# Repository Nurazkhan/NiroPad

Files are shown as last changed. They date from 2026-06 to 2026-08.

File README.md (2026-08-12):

# NiroPad
Simlple macropad to make your computer usage even faster.

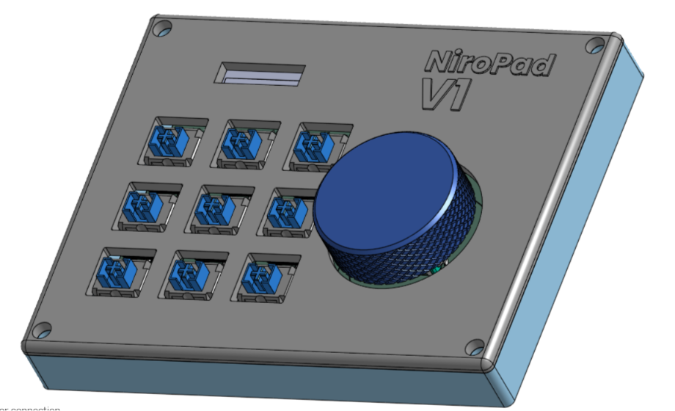
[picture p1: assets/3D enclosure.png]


I made this macropad with the help of hackClub. You can find useful references/examples in [Hackpad]([url](https://stardance.hackclub.com/missions/hackpad)) section.
## Features
* 128x32px for cool animations.
* 9 Cherry MX style Keys for best experience.
* 1 EC11 encoder to control with accuracy.
* Bright 18 RGB LEDS to make it GLOW. (9 for underglow, 4 under encoder, 4 near display, 1 under display)
* 3D printed perfect case with personal mentions.
* QMK Firmware

## CAD Model
CAD consists of a total of 3 parts: Case, Cover, Knob.
The case and the cover for it fit together with 4*M3 screws and heatset inserts.
The knob is attached to the encoder by friction.
The case has space for keys and displays, so it fits perfectly.
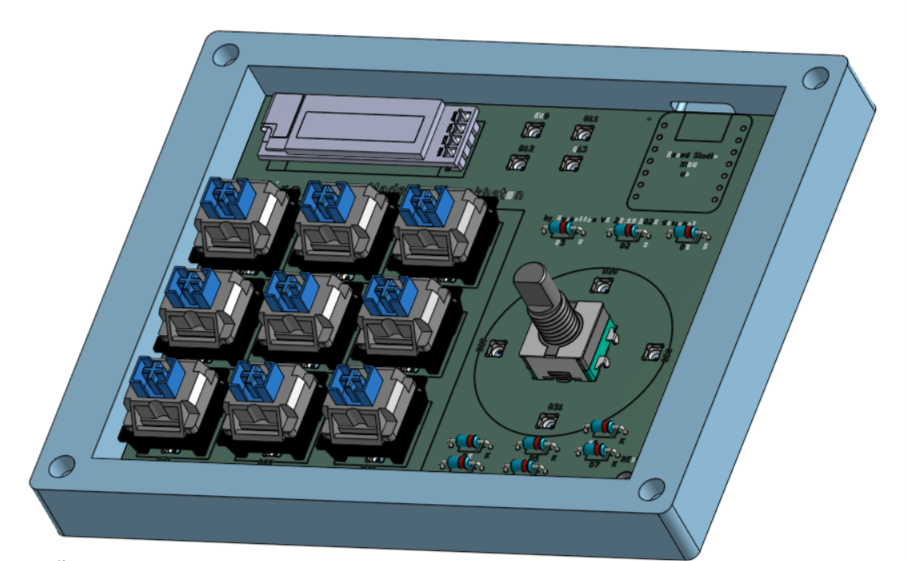
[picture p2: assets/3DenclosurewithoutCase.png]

Made in OnShape. by Nurazkhan (me).

## PCB
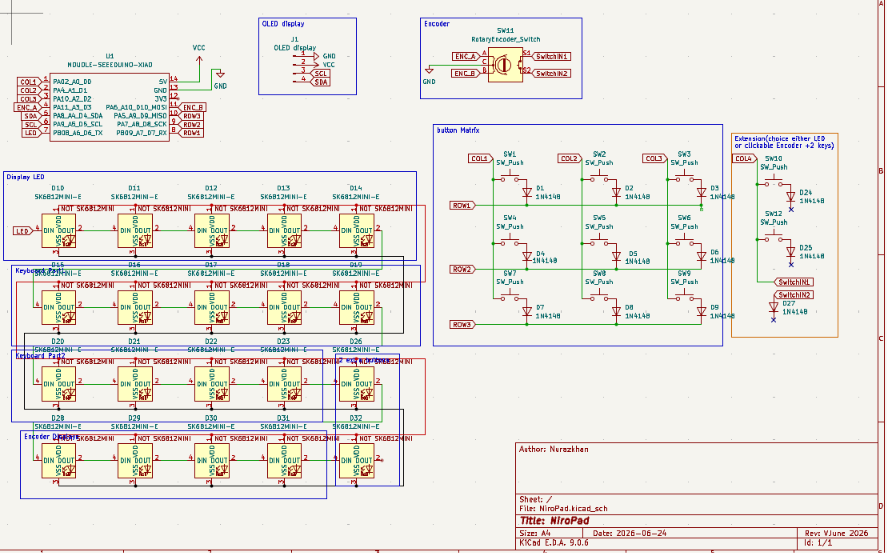
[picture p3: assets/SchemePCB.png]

Schematic was made in KiCad.
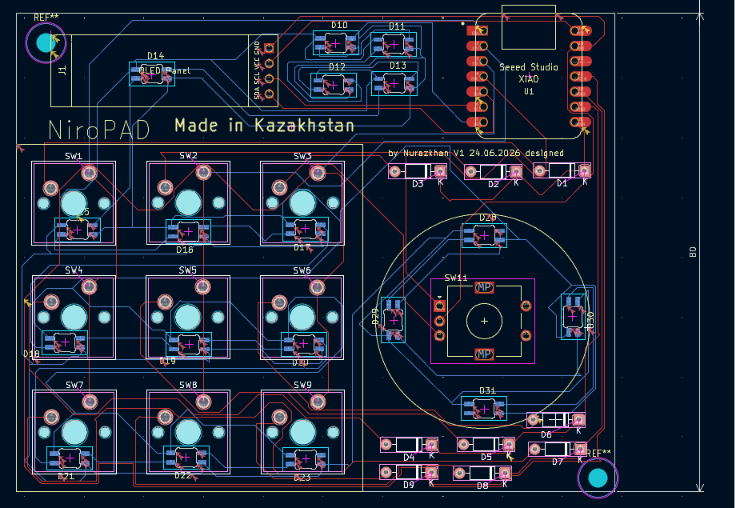
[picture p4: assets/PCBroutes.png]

PCB routing was also made in KiCad Software. Footprints for keys were imported from recommended resources; you can also find [it]([url](https://github.com/sszczep/kicad-libraries)).

## Firmware Overview
The NiroPad Works on QMK firmware.
Main functions are:
* 9 keys for the number section. (My laptop doesn't have a separate keyboard section for numbers).
* Encoder to control volume.
* Dynamic LED control based on CAPS LOCK state.
* OLED showing the mode of the keyboard.
In the future, have to add more functions (changing modes from number sections to shortcuts, or media control, etc.
Also, planning to add animations to the OLED display.

## BOM
 * 9 Cherry MX style switches
 * 9 1N4148 diodes
 * 1 Custom PCB
 * 0.91 SSD1306 OLED display 128x32px
 * Xiao Speeed RPI2040 microcontroller
 * 3d printer enclosure (top and bottom) and knob for encoder
 * EC11 Encoder
 * 4 M3*16mm screws
 * 4 M3*5m*4mm heatset inserts

The process of designing and creation you can see in the journals folder.

Thank you!
#hackClub

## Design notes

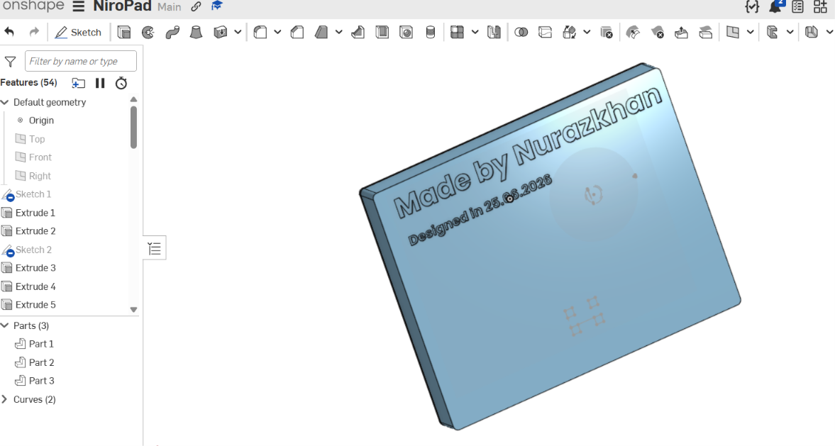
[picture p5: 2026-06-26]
assets/Back.png

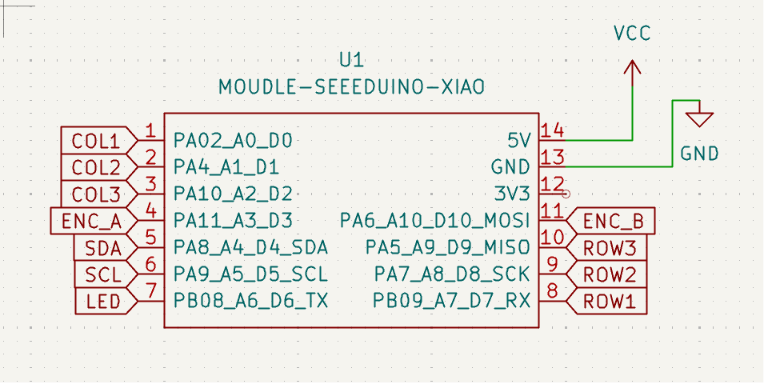
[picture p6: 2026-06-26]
assets/RPI2040scheme.png

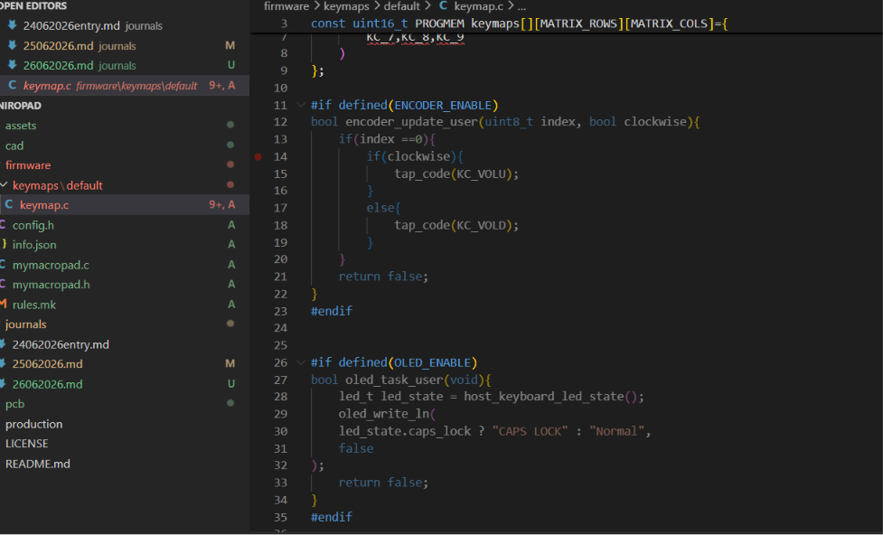
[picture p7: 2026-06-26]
assets/codeQMK.png

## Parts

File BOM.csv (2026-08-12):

Item Name | Qty | Price (total) (USD) | Item link | Notes
Cherry MX style switches | 9 | $9.25 | https://aliexpress.ru/item/32839844484.html?sku_id=65063435222 | This is part of MacroPad Kit
1N4148 diodes | 9 | $0.45 | https://aliexpress.ru/item/1005003194692663.html?sku_id=12000024603253281 | This is part of MacroPad Kit
Custom PCB | 1 |  |  | This is part of MacroPad Kit. Made by third parties(JLCPCB, PCBWAY)
0.91 SSD1306 OLED display 128x32px | 1 | $1.64 | https://aliexpress.ru/item/1005008472586580.html?sku_id=12000045297338933 | This is part of MacroPad Kit
Xiao Speeed RPI2040 microcontroller | 1 | $8.00 | https://aliexpress.ru/item/1005007427287029.html?sku_id=12000040716641980 | This is part of MacroPad Kit
3d printer enclosure (top and bottom) and knob for encoder |  |  |  | This is part of MacroPad Kit (3d printed)
EC11 Encoder | 1 | $0.67 | https://aliexpress.ru/item/1005006693443387.html?sku_id=12000048311239356 | This is part of MacroPad Kit
M3*16mm screws | 4 | $2.16 | https://aliexpress.ru/item/1005002364568213.html?sku_id=12000020355723657 | This is part of MacroPad Kit
M35m4mm heatset inserts | 4 | $1.41 | https://aliexpress.ru/item/1005008666672949.html?sku_id=12000046157335344 | This is part of MacroPad Kit
Total Price (USD): | $14.33

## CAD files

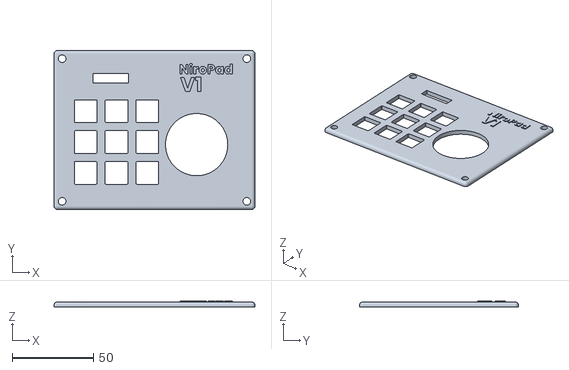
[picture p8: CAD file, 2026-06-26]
production/NiroPad - EnclosureTop.stl
124.0 x 98.0 x 3.50

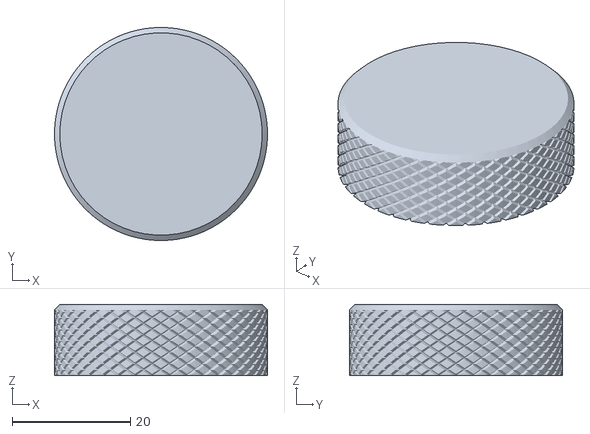
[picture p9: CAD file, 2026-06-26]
production/NiroPad - Knob.stl
36.0 x 36.0 x 12.0

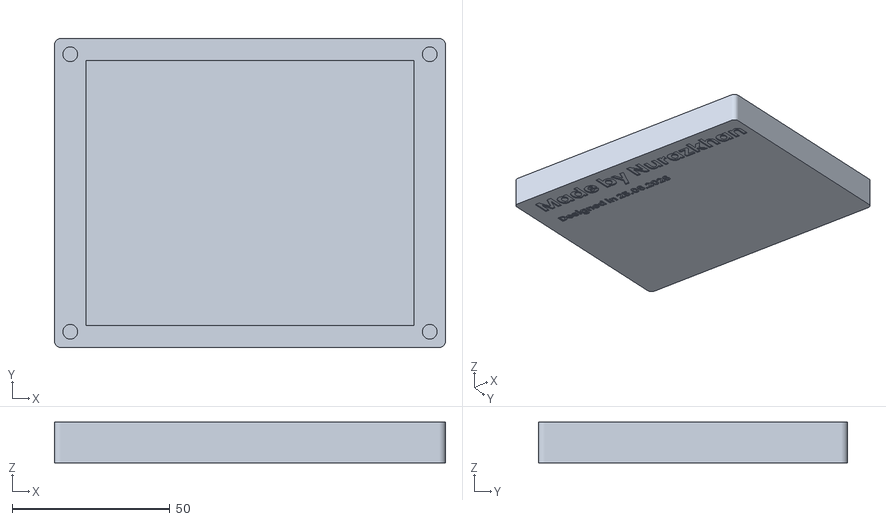
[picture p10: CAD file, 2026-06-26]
production/NiroPad - EnclosureBack.stl
124.0 x 98.0 x 13.0

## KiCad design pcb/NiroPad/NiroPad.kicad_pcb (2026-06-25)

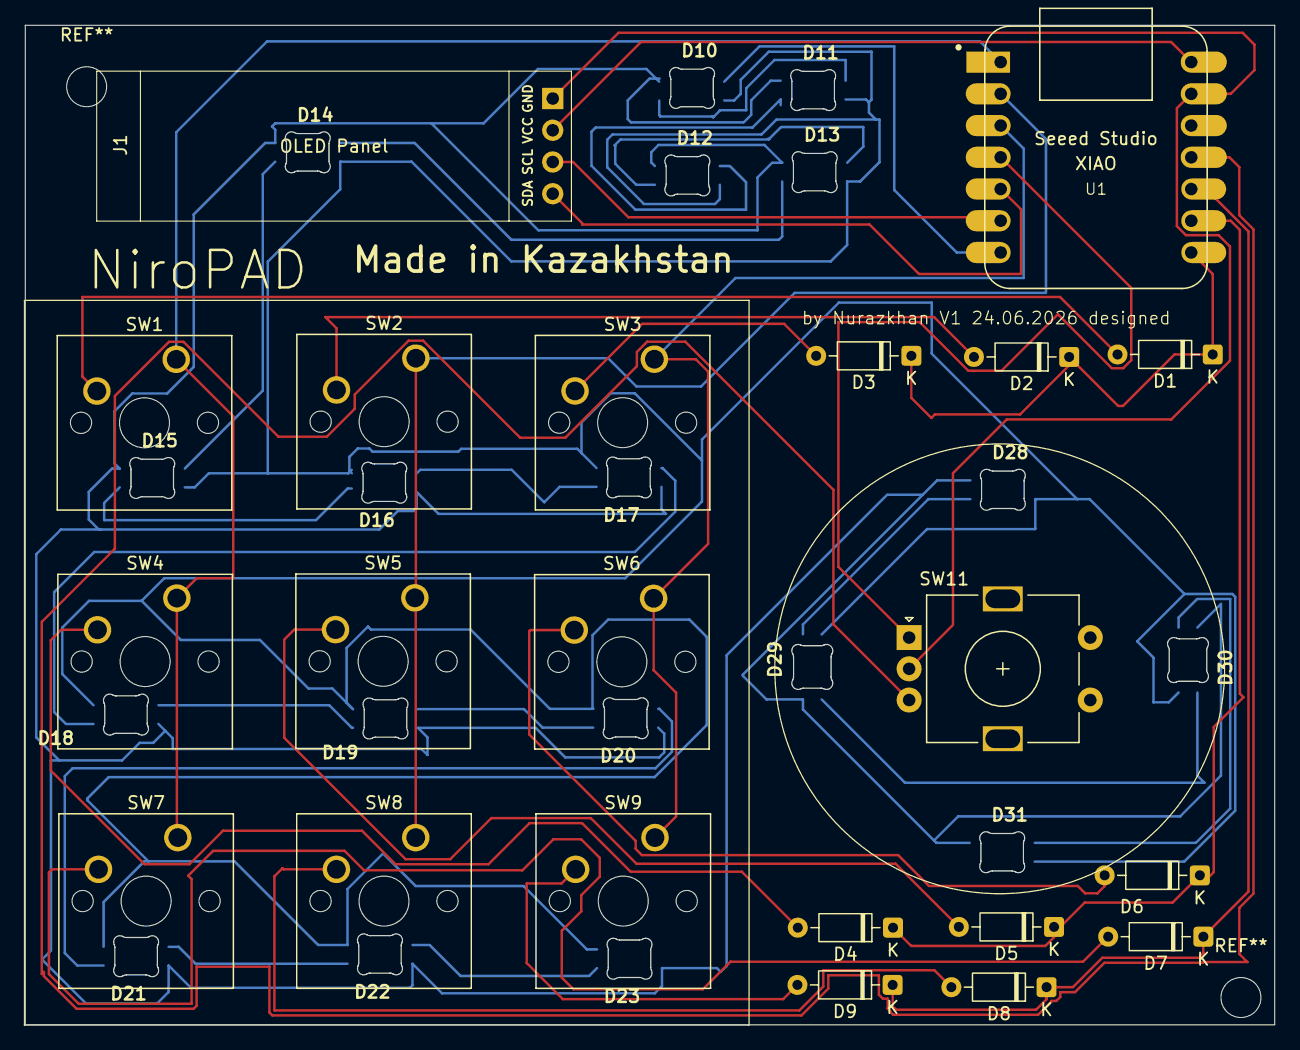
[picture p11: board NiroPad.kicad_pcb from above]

Board: 2 copper layers, 100.0 x 80.0 mm, 39 parts (0 on the bottom side), 40 nets.

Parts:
D1, D2, D3, D4, D5, D6, D7, D8, D9: 1N4148; D_DO-35_SOD27_P7.62mm_Horizontal
D10, D11, D12, D13, D14, D15, D16, D17, D18, D19, D20, D21, D22, D23, D28, D29, D30, D31: SK6812MINI-E; SK6812MINI-E_fixed
J1: OLED display; SSD1306-0.91-OLED-4pin-128x32
SW1, SW2, SW3, SW4, SW5, SW6, SW7, SW8, SW9: SW_Push; footprint
SW11: RotaryEncoder_Switch; RotaryEncoder_Alps_EC11E-Switch_Vertical_H20mm
U1: MOUDLE-SEEEDUINO-XIAO; XIAO-Generic-Hybrid-14P-2.54-21X17.8MM

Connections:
COL1: SW1.1, SW4.1, SW7.1, U1.1 (PA02_A0_D0)
COL2: SW2.1, SW5.1, SW8.1, U1.2 (PA4_A1_D1)
COL3: SW3.1, SW6.1, SW9.1, U1.3 (PA10_A2_D2)
ENC_A: SW11.A, U1.4 (PA11_A3_D3)
ENC_B: SW11.B, U1.11 (PA6_A10_D10_MOSI)
GND: J1.1, SW11.C, U1.13 (GND)
LED: D10.4 (DIN), U1.7 (PB08_A6_D6_TX)
unnamed: D1.2 (A), SW1.2
unnamed: D2.2 (A), SW2.2
unnamed: D3.2 (A), SW3.2
unnamed: D4.2 (A), SW4.2
unnamed: D5.2 (A), SW5.2
unnamed: D6.2 (A), SW6.2
unnamed: D7.2 (A), SW7.2
unnamed: D8.2 (A), SW8.2
unnamed: D9.2 (A), SW9.2
unnamed: D10.2 (DOUT), D11.4 (DIN)
unnamed: D10.1 (VDD), D11.1 (VDD), D12.1 (VDD), D13.1 (VDD), D14.1 (VDD), D15.1 (VDD), D16.1 (VDD), D17.1 (VDD), D18.1 (VDD), D19.1 (VDD), D20.1 (VDD), D21.1 (VDD), D22.1 (VDD), D23.1 (VDD), D28.1 (VDD), D29.1 (VDD), D30.1 (VDD), D31.1 (VDD)
unnamed: D10.3 (VSS), D11.3 (VSS), D12.3 (VSS), D13.3 (VSS), D14.3 (VSS), D15.3 (VSS), D16.3 (VSS), D17.3 (VSS), D18.3 (VSS), D19.3 (VSS), D20.3 (VSS), D21.3 (VSS), D22.3 (VSS), D23.3 (VSS), D28.3 (VSS), D29.3 (VSS), D30.3 (VSS), D31.3 (VSS)
unnamed: D11.2 (DOUT), D12.4 (DIN)
unnamed: D12.2 (DOUT), D13.4 (DIN)
unnamed: D13.2 (DOUT), D14.4 (DIN)
unnamed: D14.2 (DOUT), D15.4 (DIN)
unnamed: D15.2 (DOUT), D16.4 (DIN)
unnamed: D16.2 (DOUT), D17.4 (DIN)
unnamed: D17.2 (DOUT), D18.4 (DIN)
unnamed: D18.2 (DOUT), D19.4 (DIN)
unnamed: D19.2 (DOUT), D20.4 (DIN)
unnamed: D20.2 (DOUT), D21.4 (DIN)
unnamed: D21.2 (DOUT), D22.4 (DIN)
unnamed: D22.2 (DOUT), D23.4 (DIN)
unnamed: D28.2 (DOUT), D29.4 (DIN)
unnamed: D29.2 (DOUT), D30.4 (DIN)
unnamed: D30.2 (DOUT), D31.4 (DIN)
ROW1: D1.1 (K), D2.1 (K), D3.1 (K), U1.8 (PB09_A7_D7_RX)
ROW2: D4.1 (K), D5.1 (K), D6.1 (K), U1.9 (PA7_A8_D8_SCK)
ROW3: D7.1 (K), D8.1 (K), D9.1 (K), U1.10 (PA5_A9_D9_MISO)
SCL: J1.3, U1.6 (PA9_A5_D5_SCL)
SDA: J1.4, U1.5 (PA8_A4_D4_SDA)
VCC: J1.2, U1.14 (5V)

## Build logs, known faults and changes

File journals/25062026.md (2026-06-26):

# second entry

This entry is for 3d enclosure part. Actualy it was hard. very hard.
I chose onShape because previously have worked with it. But, I don't is it my laptop getting laggy , so that even browser is getting slow, so it was high cortisol task :(

First I followed guide made enclosure little bit bigger than pcb to keep spacefor printer inaccuracy 4 mm.
My pcb is 8 and 10cm, so ass guide write it must be at max 20x10x10. So I had to made sure the 8cm part shouldnt be more than 10. Also for clear visibilite and test I imported the pcb with all 3d models to onShape from KiCad, I suppose it was amazing desicion. It indeed helped when designing the typeC port and knob for encoder.

I used some website also showed in the guide to genereate dxf file for me, so I extruded it from there. Should have been easiest part, but at first I messed up with location of switches itself so Had to calibrate offset.

The knob part was too easy actually. Just cylynder with hole for encoder. It was boring, so I searched for way to add texture on knob. And learned about knurling. That was the interesting part, and most laggy part. my bad internet connection + laggy laptop made it the longest part, when it tried to render 36 element consisting sweep in cylinder in both direction.

Another hard part for me was assembly part to see how all together would look like. I used fastened mates for that, but I am not sure why I kept messing up, it was hard to just put them together. But after dedicated time I got satisfiable result. Didn't want to stay to long in this part, so moved.

The display part and little holes for indicators was easy to do, I aligned with pcb model actually I suppose it was good.
I wanted to add a lot of text actually. But for each text I had to make one sketch, and it was too much time. Not sure why that happened, but i added only few texts. and mention hack club of course :)

That is how I made that 3d enclosure part.

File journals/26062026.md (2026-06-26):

The QMK firmware

#Third Entry

The worst and most unclear part I've countered.

The only thing guide has is just link to documentation, which was so unclear.
Because document had so many thing toolbox, cli, msys, something for advanced users, I didn't know even where to start.

I tried to read, I got confused and searched for the youtube. Saw some people, but they wrote to some keyboard on different microcontroller, and to be honest they were also unclear.
So, again came to documentation tried to follow getting started and setup parts, but still couldn't get sense of it. 
So, I opened github of the example orpheusPAD, and get some sense of what to write. Still I saw only result not the way how to start. So, I decided to use AI. 
It actually helped a lot, I installed the QMK MSYS and setted up and created new keyboard there.

Then, again opened documentation and went to section using QMK part.
Get basic sense and skimmed through the keycodes out there. My laptop doesnt have the numbers section in the right side, and I thought it will be handy, especially when I write with my native language. Because when I do that the numbers are top are not printing numbers but lnaguage specific letters, So i can write button. so it was easy, just KC_1-9,

Encoder and LEDs I am not sure if this correct. I didnt want to just copy from github of example, and just tried to write how it should work after skimming the documentation. Encoder will change volume and led will be always red. and Oled display will shows if caps lock pressed, my laptop doesnt have indicator and sometimes it is disturbing.
as i dont have macropad in hand right now, I have no motivation to experiment, as I can't even check.
But when I actually get it I am definitely improve QMK.
1. I want to exact LED light when button is pressed. 
2. Also, same when encoder gets rotated they leds under it should glow.
3. Finally, I want it glow when caps lock state changes

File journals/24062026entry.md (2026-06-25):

# First Entry

I started from Idea, at first I wanted to make interesting design 
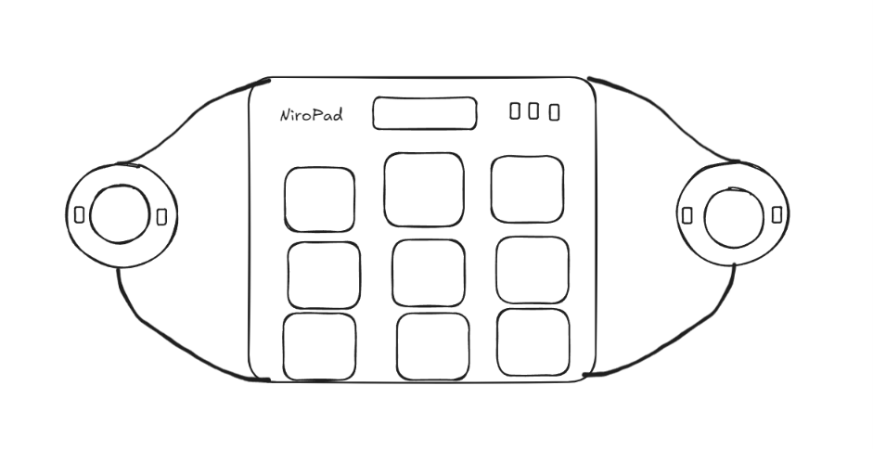
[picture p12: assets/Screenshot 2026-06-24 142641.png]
FirstDesign

I thought it will be unique to me, and I can even play games as it includes 2 encoders, 9 buttons, display and LEDs. I planned to use LEDs not only behind keyboard, but as indicator of level and so on, so I placed several near display.

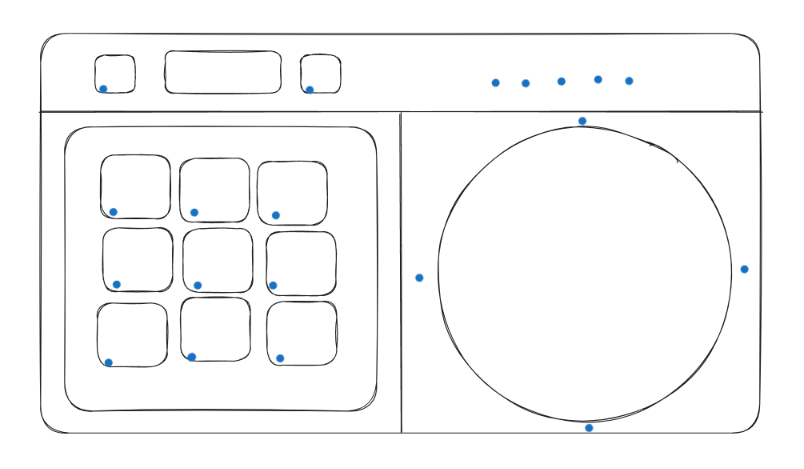
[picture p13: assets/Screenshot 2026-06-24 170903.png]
SecondDesign
But when I started making schematics, I found that I cant fit all this together as there only 11 pins. Also, I learned about button matrix, interesting actually. After little search I found actually there are ways to include the encoder itself as an switch in button matrix, but I also found that it might cause problems. Eventually, I decided to remove second encoder, and changed design.
This design is more similar to ones you find in gallery.
But the main uniqueness was in 2 buttons near display and indicators all over the place.
I tried that and made button matrix of 4columns and 3 rows. but again found out that I can not add column 4 or I should remove LEDs. Column 4 was responsible for 2 switches near display and encoder switch. Though I really wanted to add encoder switch, I had to make choice. My choice was to leave LEDs.
Just for reminder 
Encoder needs 3 pins, (when switch used for matrix)
Leds only 1
Switch matrix 3x3 needs 6 pins
Display needs 2.
I didnt use encoder switch so it took only 2. Finally 2 +1+6+2=11 all pins are used.

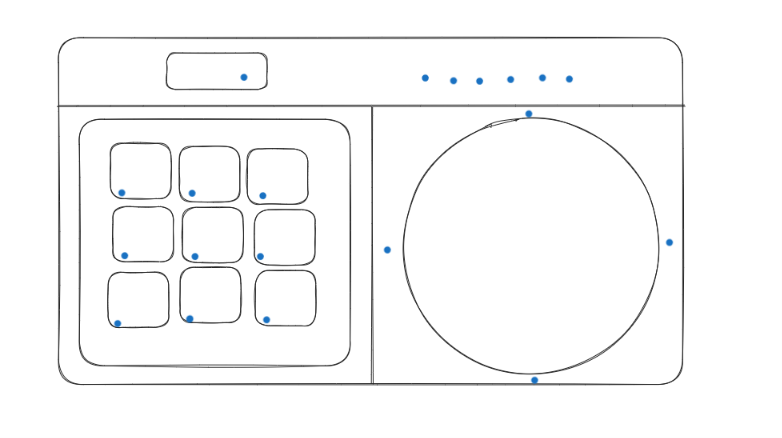
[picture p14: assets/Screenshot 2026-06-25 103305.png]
ThirdDesign
So final design looked like this 

Then I assigned footprints, mostly from Kicad builtin library and from care package.
The resources told to use 4pin header for oled, but I used actualy footprint so I won't mess up with sizes.

The pcb routing actually was hardest tasks. I had so many components had to fit in 80*100mm.
As expected from me now, I am not pro and my main task was to connect, even if not perfectly.
Though I tried to shorten routes, don't place them too close to each other, there are long routes that are close to each other.

I multiple times doubted my decision of choosing LEDs. They were all over the place, and they stood behing longest routes. Nevertheless, I could finish it. Finally, I added 3D model to each footprint, mostly searched from grabCAD. I Wanted to see my PCB in 3d.
I didn't knew how to update footprint 3d models, I though making it manually but when I saw 20 leds, I searched for better way , and actually found that there were actually function for that.

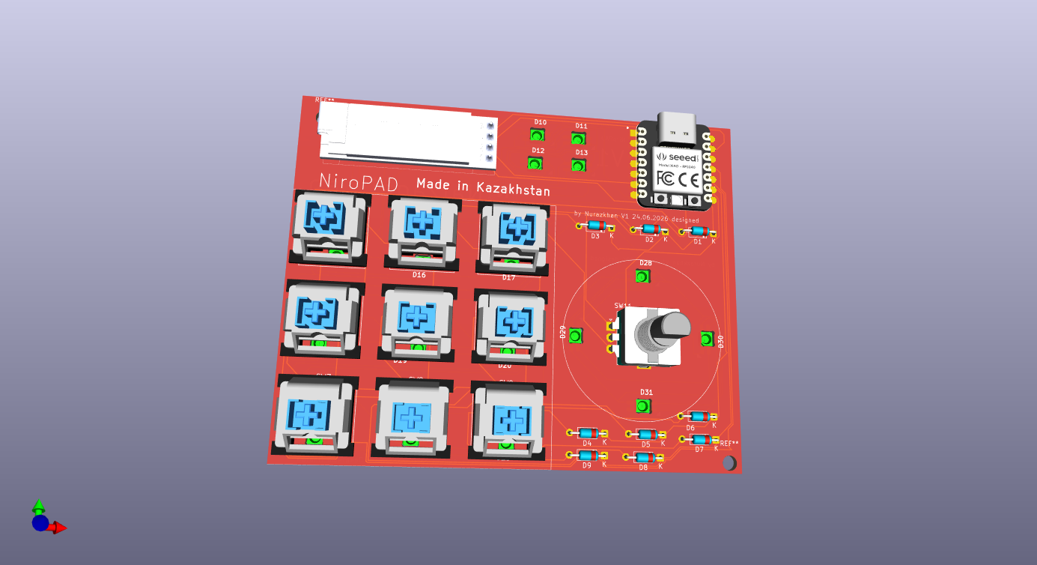
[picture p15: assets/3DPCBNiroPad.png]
FinalPcb
Finally, my pcb

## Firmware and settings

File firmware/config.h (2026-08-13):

#pragma once
#define I2C_DRIVER I2CD1
#define I2C1_SDA_PIN GP6
 #define I2C1_SCL_PIN GP7
#define RGBLED_NUM 20
// Ensure RGBLIGHT_LED_COUNT is available for drivers that expect it
#ifndef RGBLIGHT_LED_COUNT
#define RGBLIGHT_LED_COUNT RGBLED_NUM
#endif

// USB identity (required by the USB descriptor)
// You can change these to your actual VID/PID if you have them.
#ifndef VENDOR_ID
#define VENDOR_ID 0xFEED
#endif
#ifndef PRODUCT_ID
#define PRODUCT_ID 0x6060
#endif
#ifndef DEVICE_VER
#define DEVICE_VER 0x0001
#endif
#ifndef MANUFACTURER
#define MANUFACTURER "Nuraz"
#endif
#ifndef PRODUCT
#define PRODUCT "NiroPad"
#endif

#define ENCODER_A_PINS { GP29 }
#define ENCODER_B_PINS { GP3 }

#define WS2812_DI_PIN GP0

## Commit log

2026-06-25 V0.6 Scheme + PCB + board 3D
    [NiroPad.kicad_pcb, NiroPad.kicad_sch]
2026-06-26 PCB+3d+QMK - everything done?
    [NiroPad - EnclosureBack.stl, NiroPad - EnclosureTop.stl, NiroPad - Knob.stl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]
2026-08-12 BOM included
    [BOM.csv]
2026-08-13 production folder fix
    [NiroPad - EnclosureBack.stl, NiroPad - EnclosureTop.stl, NiroPad - Knob.stl]
